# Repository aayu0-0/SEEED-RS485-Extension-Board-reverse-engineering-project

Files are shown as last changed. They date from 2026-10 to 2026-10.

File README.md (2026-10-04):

# Seeed Studio RS485 Extension Board — Reverse Engineering

A reverse-engineering and PCB recreation project of the **Seeed Studio RS485 Extension Board**.

The objective of this project is to understand the original board's electrical architecture, reproduce its schematic and PCB layout in KiCad, and generate a fabrication-ready design.

---

## 📌 Project Overview

This project involves analyzing the original Seeed Studio RS485 Extension Board and recreating its:

- Electrical schematic
- Power supply architecture
- RS485 communication interface
- Protection circuitry
- PCB layout
- Component footprints
- Manufacturing files

The recreated design is developed entirely in **KiCad**.

---

## 🎯 Objectives

- Reverse engineer the original RS485 extension board
- Understand the power and communication architecture
- Recreate the schematic in KiCad
- Select appropriate components and footprints
- Recreate the PCB layout
- Verify electrical connections and design rules
- Generate Gerber and drill files for PCB fabrication

---

## 🔧 Hardware

### Main Interfaces

- RS485 communication interface
- External power input
- Microcontroller/interface connection
- Protection circuitry

### Design Considerations

The design includes consideration for:

- RS485 differential signalling
- 120 Ω termination
- Fail-safe biasing
- Power regulation
- Reverse-polarity / transient protection
- Proper PCB grounding
- Controlled differential routing

---

## 🖥️ Software & Tools

| Tool | Purpose |
|---|---|
| **KiCad** | Schematic and PCB design |
| **Git** | Version control |
| **GitHub** | Project hosting |
| **Datasheets** | Component verification |

---

## 📁 Repository Structure

```text
.
├── Home_Automation_v1.kicad_pro
├── Home_Automation_v1.kicad_sch
├── Home_Automation_v1.kicad_pcb
│
├── Home_Automation_v1.pretty/
│   └── Custom footprints
│
├── Final_Files/
│   ├── Gerber files
│   ├── Drill files
│   └── Gerber job file
│
└── README.md

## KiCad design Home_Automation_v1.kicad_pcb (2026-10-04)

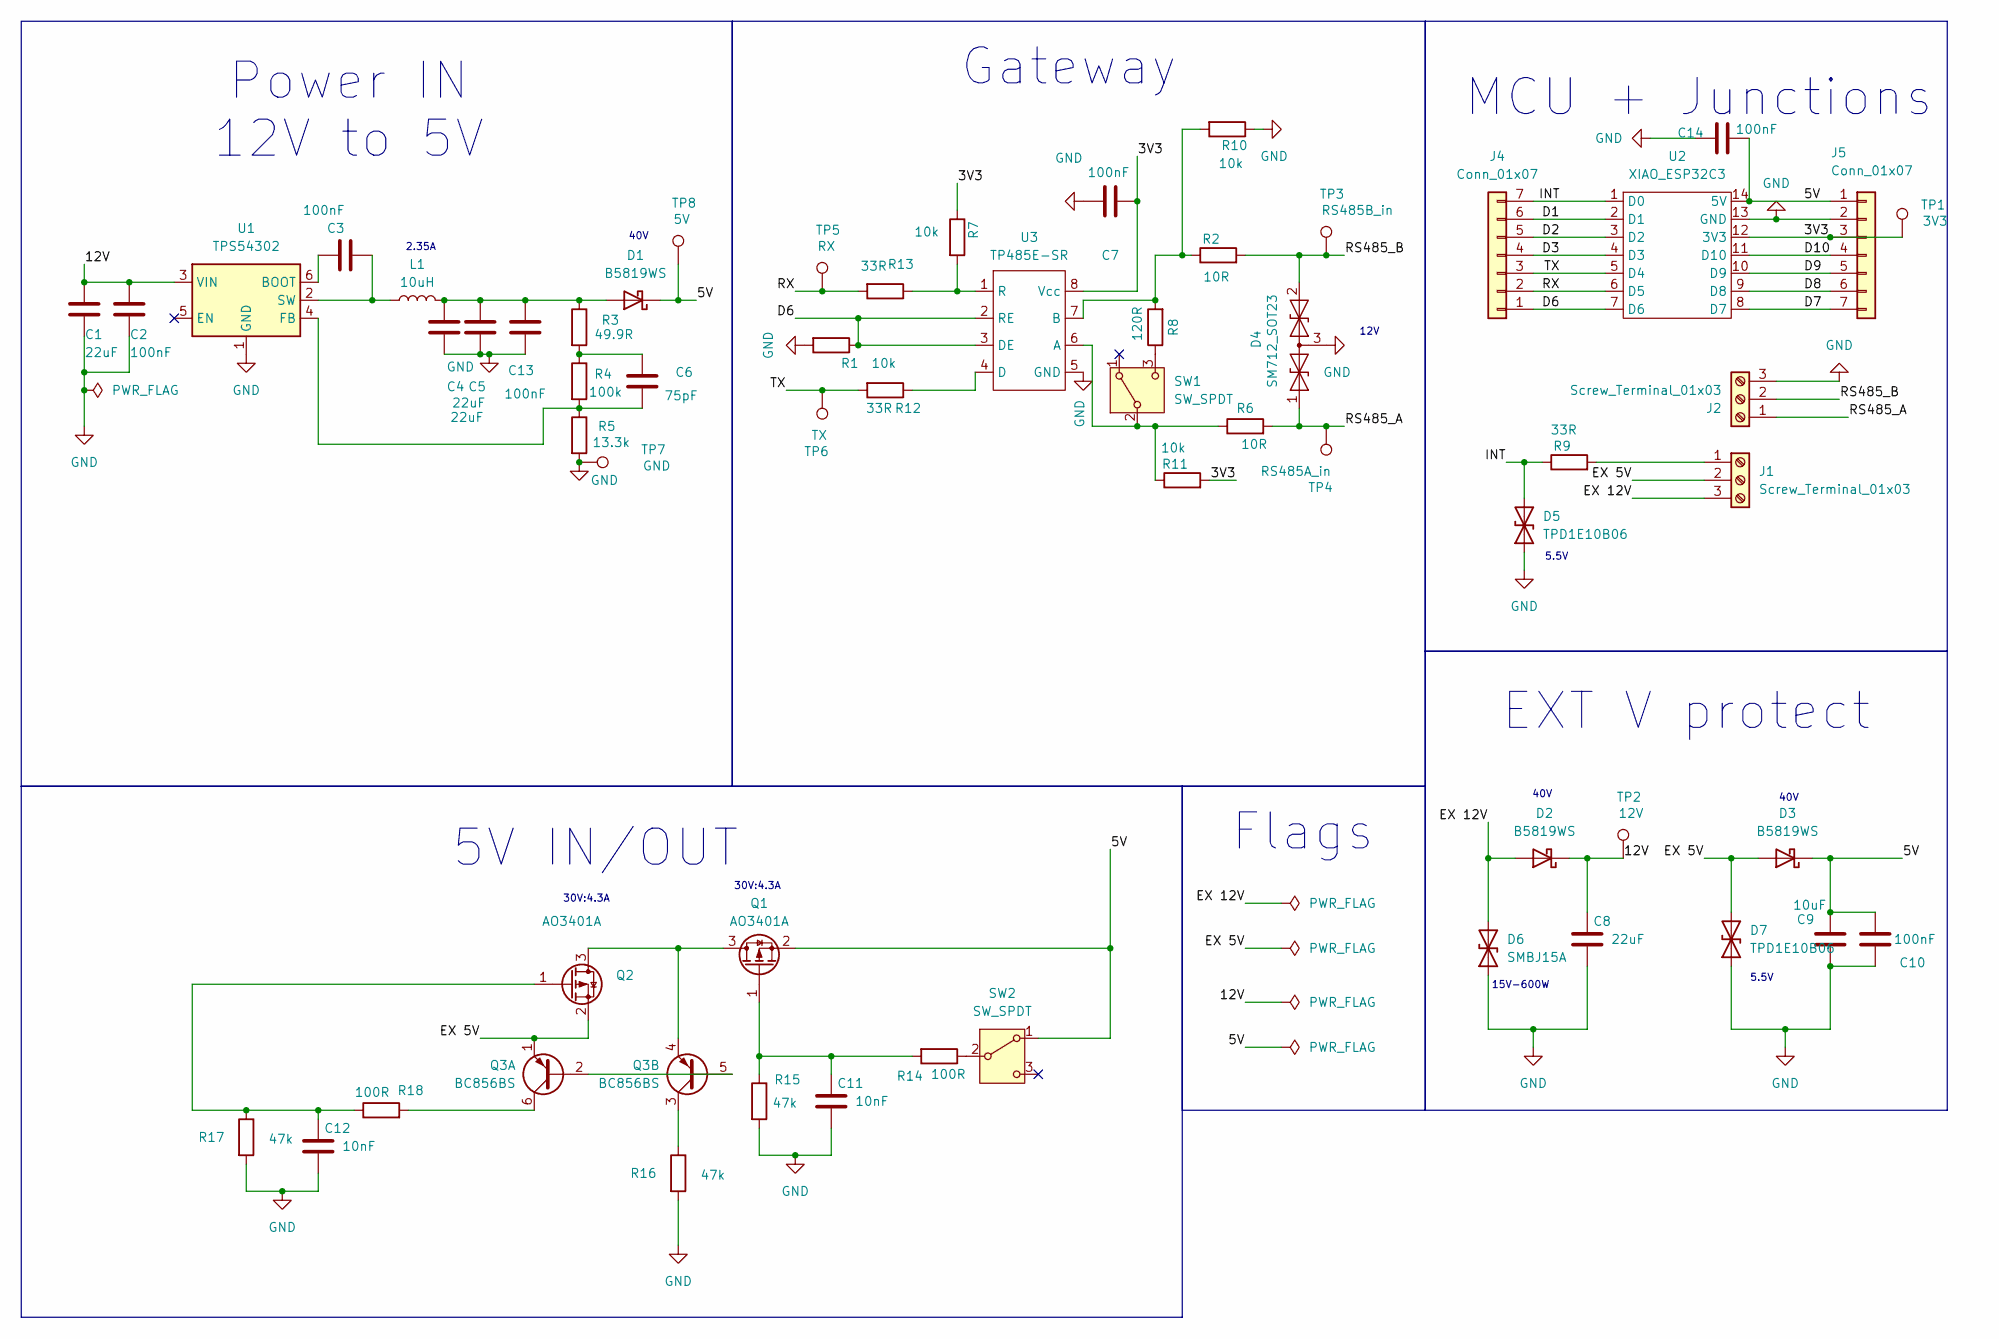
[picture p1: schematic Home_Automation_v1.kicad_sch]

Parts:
C1, C4, C5, C8: 22uF; C_0805_2012Metric
C2, C3, C7, C10, C13, C14: 100nF; C_0603_1608Metric
C6: 75pF; C_0603_1608Metric
C9: 10uF; C_0603_1608Metric
C11, C12: 10nF; C_0603_1608Metric
D1, D2, D3: B5819WS; D_SOD-323
D4: SM712_SOT23; SOT-23
D5, D7: TPD1E10B06; Texas_DPY0002A_0.6x1mm_P0.65mm
D6: SMBJ15A; D_SMB
J1, J2: Screw_Terminal_01x03; TerminalBlock_bornier-3_P5.08mm
J4, J5: Conn_01x07; PinHeader_1x07_P2.54mm_Vertical
L1: 10uH; L_Vishay_IHLP-2525
Q1, Q2: AO3401A; SOT-23
Q3: BC856BS; SOT-363_SC-70-6
R1, R7, R10, R11: 10k; R_0603_1608Metric
R2, R6: 10R; R_0603_1608Metric
R3: 49.9R; R_0603_1608Metric
R4: 100k; R_0603_1608Metric
R5: 13.3k; R_0603_1608Metric
R8: 120R; R_0603_1608Metric
R9, R12, R13: 33R; R_0603_1608Metric
R14, R18: 100R; R_0603_1608Metric
R15, R16, R17: 47k; R_0603_1608Metric
SW1, SW2: SW_SPDT; SW-SMD_G-SWITCH_MK-12C02-G015
TP1: 3V3; TestPoint_Pad_D1.5mm
TP2: 12V; TestPoint_Pad_D1.5mm
TP3: RS485B_in; TestPoint_Pad_D1.5mm
TP4: RS485A_in; TestPoint_Pad_D1.5mm
TP5: RX; TestPoint_Pad_D1.5mm
TP6: TX; TestPoint_Pad_D1.5mm
TP7: GND; TestPoint_Pad_D1.5mm
TP8: 5V; TestPoint_Pad_D1.5mm
U1: TPS54302; SOT-23-6
U2: XIAO_ESP32C3; MCU_Seeed_ESP32C3
U3: TP485E-SR; SOIC-8_3.9x4.9mm_P1.27mm

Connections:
/3V3: C7.1, J5.3, R7.1, R11.2, TP1.1 (1_1), U2.12 (3V3), U3.8 (Vcc)
/5V: C9.1, C10.1, C14.2, D1.1 (K), D3.1 (K), J5.1, Q1.2 (S), SW2.1 (A), TP8.1 (1_1), U2.14 (5V)
/12V: C1.1, C2.1, C8.1, D2.1 (K), TP2.1 (1_1), U1.3 (VIN)
/D1: J4.6, U2.2 (D1)
/D2: J4.5, U2.3 (D2)
/D3: J4.4, U2.4 (D3)
/D6: J4.1, R1.1, U2.7 (D6), U3.2 (RE), U3.3 (DE)
/D7: J5.7, U2.8 (D7)
/D8: J5.6, U2.9 (D8)
/D9: J5.5, U2.10 (D9)
/D10: J5.4, U2.11 (D10)
/EX 5V: D3.2 (A), D7.2 (A2), J1.2, Q2.2 (S), Q3.1 (E1)
/EX 12V: D2.2 (A), D6.2 (A2), J1.3
/INT: D5.2 (A2), J4.7, R9.1, U2.1 (D0)
/RS485_A: D4.1 (A1), J2.1, R6.2, TP4.1 (1_1)
/RS485_B: D4.2 (A2), J2.2, R2.2, TP3.1 (1_1)
/RX: J4.2, R13.2, TP5.1 (1_1), U2.6 (D5)
/TX: J4.3, R12.2, TP6.1 (1_1), U2.5 (D4)
GND: C1.2, C2.2, C4.2, C5.2, C7.2, C8.2, C9.2, C10.2, C11.2, C12.2, C13.2, C14.1, D4.3 (common), D5.1 (A1), D6.1 (A1), D7.1 (A1), J2.3, J5.2, R1.2, R5.2, R10.1, R15.2, R16.2, R17.2, TP7.1 (1_1), U1.1 (GND), U2.13 (GND), U3.5 (GND)
unnamed: C6.1, R3.2, R4.1
unnamed: C4.1, C5.1, C13.1, D1.2 (A), L1.2, R3.1
unnamed: J1.1, R9.2
unnamed: Q1.3 (D), Q2.3 (D), Q3.4 (E2)
unnamed: C11.1, Q1.1 (G), R14.2, R15.1
unnamed: C12.1, Q2.1 (G), R17.1, R18.1
unnamed: Q3.2 (B1), Q3.5 (B2)
unnamed: Q3.6 (C1), R18.2
unnamed: Q3.3 (C2), R16.1
unnamed: R6.1, R11.1, SW1.2 (B), U3.6 (A)
unnamed: R8.1, SW1.3 (C)
unnamed: R14.1, SW2.2 (B)
unnamed: C3.1, U1.6 (BOOT)
unnamed: C6.2, R4.2, R5.1, U1.4 (FB)
unnamed: C3.2, L1.1, U1.2 (SW)
unnamed: R2.1, R8.2, R10.2, U3.7 (B)
unnamed: R12.1, U3.4 (D)
unnamed: R7.2, R13.1, U3.1 (R)

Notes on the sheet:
Gateway
2.35A
40V
30V:4.3A
MCU + Junctions
40V
5V IN/OUT
5.5V
15V-600W
Flags
5.5V
12V
EXT V protect
Power IN 12V to 5V

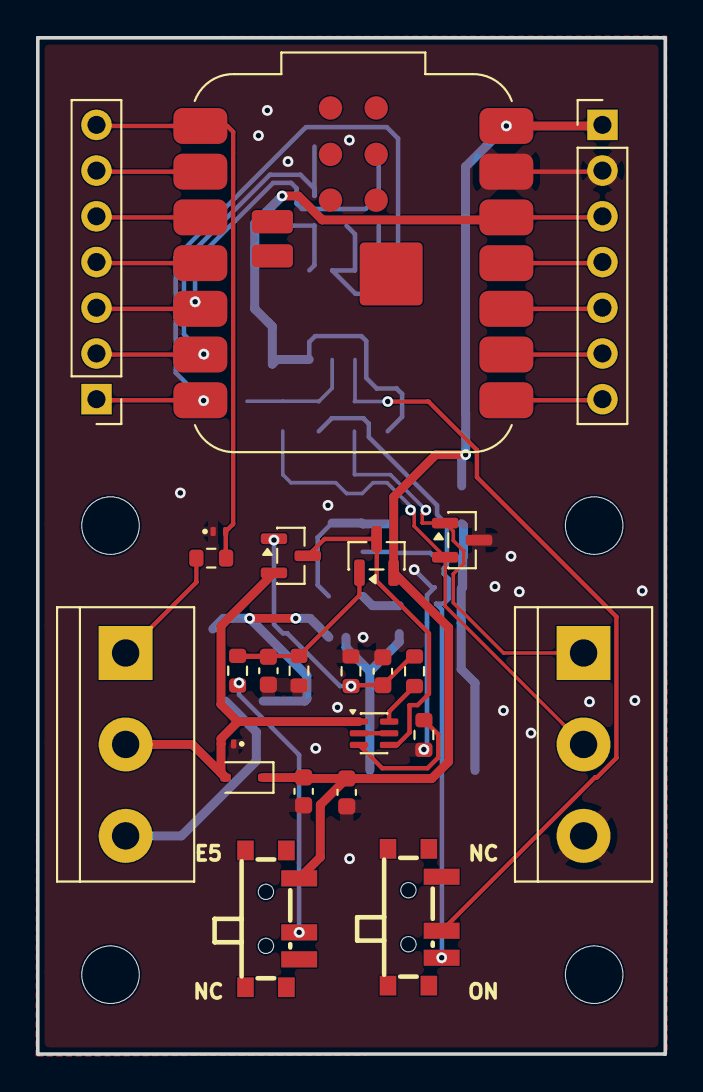
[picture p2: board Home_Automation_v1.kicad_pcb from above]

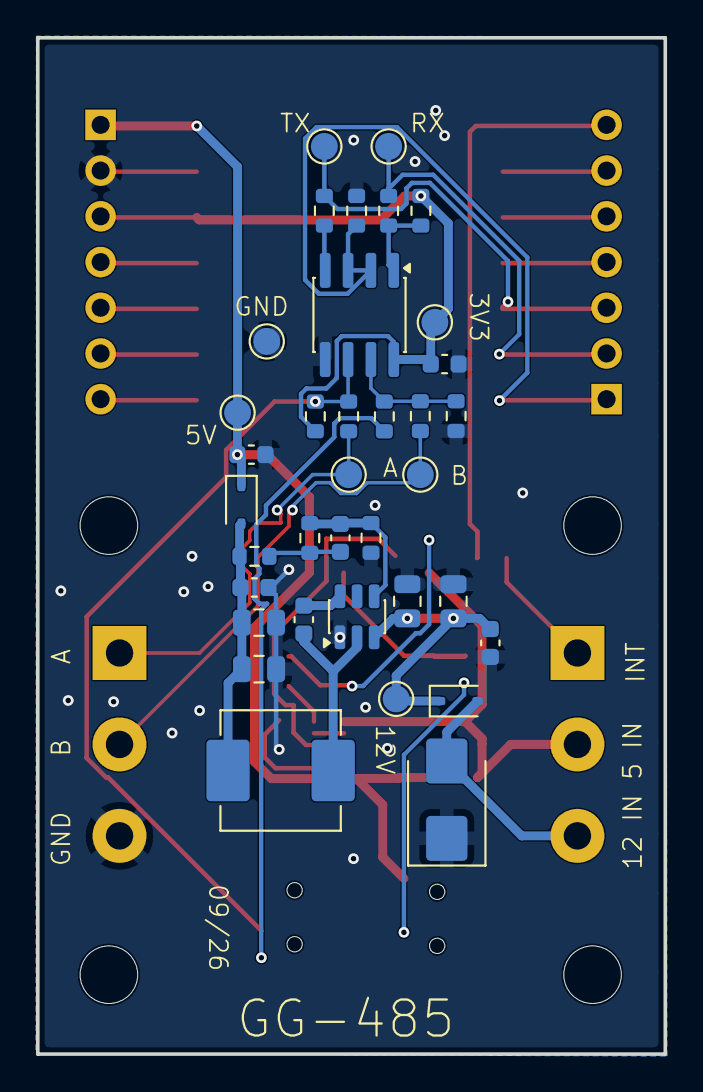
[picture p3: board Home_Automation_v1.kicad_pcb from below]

Board: 2 copper layers, 34.9 x 56.5 mm, 60 parts (36 on the bottom side), 37 nets.
